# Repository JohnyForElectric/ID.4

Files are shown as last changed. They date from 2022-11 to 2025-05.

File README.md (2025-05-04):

## This repo discusses various appearance and convenience updates, tweak and retrofits for ID.4/ID.5 car family. 

_None of these are endorsed by the manufacturer, all content is provided for informational purposes only, we do not take any responsibility or liability for any damage, loss, injury or voiding warranty._

> [!TIP]
> Please, check our VW ID Talk Podcast https://www.youtube.com/@vwidtalkdotcom

Why? To make us feel better about what we drive, some of us would like to make usability changes (retrofit 360 camera system, better audio,...), improve convinience (foldable mirrors, open/closde all windows with key,...), protect the car (paint protection film, door sills,...) or change the appearance and comfort (different wheels, "black" package,...). It's up to everyone's taste. Below are some ideas...

> **Desclaimer:** All content is provided for informational purposes only. We assume no responsibility for any damage, loss, injury, or voided warranty resulting from modifications. Proceed at your own risk.

### Core principles

1.	Use high quality OEM parts, if OEM not availbale, make it look like it "belongs there"
2.	Do not touch or interfere with any high-voltage components

Below are 3 categories of changes by the level of difficulty we discuss on this page - 

| Type | Description | Simplicity | Notes |
| :--- | :--- | :--- | :---  |
| [Updates](#Updates) | OEM or vendor components manufactured for the ID. car family | L100 (Simplest) | Simple to install by following installation manaual |
| [Tweaks](#Tweaks) | Modification of existing OEM compopnents | L200-300 (Harder) | Usually no or very little "coding" or "adaptation" necessary|
| [Retrofits](#Retrofits) | Installing OEM components that were not in the vehicle for the current model year or not availbale in country of purchase | L400+ (Very hard) | Custom harness, SMD soldering and extensive "coding" / "adaptation" necessary|

### Retrofits
Retrofit is a change or addition of OEM componenets that were not available when the car was purchased. Typically, options not available in the US market or in the previous model years. 
_None of these are endorsed by the manufacturer, all content is provided for informational purposes only, we do not take any responsibility or liability for any damage, loss, injury or voiding warranty._

| Project | Description | OEM HW Feasibility | Coding Feasibility | Doable? | Works in ID.Software version and MY? | WVIDTalk Forum links |
| :--- | :--- | :--- | :---  | :--- | :--- | :---
| [Euro Style Tail Lights "ID.Light"](</Retrofits/Euro%20Style%20Tail%20Lights.md>) | Rear Euro Style top trim tail lights with animations | Feasible / Done | Feasible / Done | Yes (with workaround) | 2.1, 3.1 | [VWIDTalk Discussion](<https://www.vwidtalk.com/posts/119787/>) |
| Capacitative button replacement | Headlights, vision and multimedia capacitrative swap for Skoda Enyaq/Elroq | Feasible / Done | Feasible / Done | Electrically compatible, requires LOT of physical interfaces and cutting out parts of dash | No coding needed | [VWIDTalk Discussion](<https://www.vwidtalk.com/threads/half-way-on-capitative-buttons-replacement.18355/?post_id=316986#post-316986>) |
| 360 Area View Camera | Install 360 camera system with 4 cameras | Feasible, extra 4 cameras and 360 module required | Feasible | Yes (with caveats) | POC tested with 3.2 | [VWIDTalk Discussion](<https://www.vwidtalk.com/posts/275796/>) |
| GTX Style Diamond Pattern Accent Lights | Front bumper accent lights | Feasible | Feasible | Yes - front bumber removal required | N/A |  [VWIDTalk Discussion](<https://www.vwidtalk.com/posts/152339/>) |
| Q4 e-tron AC Control Head | A/C control panel from Q4/A3 | Possibly feasible based on the version of AC (J979) module | TBD | Tested on 2.1 - the display was ready only | TDB |  [VWIDTalk Discussion](<https://www.vwidtalk.com/posts/112946/>) |
| Ventilated front seats | Front seat ventilation | Feasible - requires 4 fans, wiring and soldering in the CECM control unit | Known, needs validation | There is a plan b (availbale conveniece CAN decoder) to avoing soldering in the CECM. Needs permananet seat cushion modification. | Validated in 3.2. |  [VWIDTalk Discussion](<https://www.vwidtalk.com/posts/292287/>) |
| Heated rear seats | Add seat heaters froi the rear seats (4 heating elements) and controller to the middle console | TBD - depands on the AC module (J979) version | Doable is supported in HW | N/A | |  [VWIDTalk Discussion](<https://www.vwidtalk.com/posts/279775/>) |
| GTI/GLI/R Steering Wheel Controls | Steering wheel buttons with "R" and "Heated Steering Wheel" buttons | Feasible | Coding & ACC Adaptation needed | N/A | N/A |  [VWIDTalk Discussion](<https://www.vwidtalk.com/posts/112011/>) |

   _OEM HW (original equipment manufacturer hardware) feasibility - determines if the original hardware (parts, control units, connectors) can be used. Coding Feasibility - determines if the existing control unit supports that project._
_None of these are endorsed by the manufacturer, all content is provided for informational purposes only, we do not take any responsibility or liability for any damage, loss, injury or voiding warranty._

### Tweaks
We define "tweak" is a change or addition where no OEM componenets exist. 

| Project | Description | Limitations
| :--- | :--- | :---
| [Driver Window Controls Haptic Feedback](</Tweaks/Driver%20Window%20Controls%20Haptic%20Feedback.md>) | Haptic feedback for the "famous" driver door window switches | All ID cars
| [Ventilated phone storage (German made cars)](</Tweaks/Ventilated%20Phone%20Storage.md>) | New fan to cool phone space and wireless charging plate | German-made ID.4 and ID.5 cars, all SW versions

### Updates
Updates use OEM or vendor components manufactured for the ID.4. 

| What | Details | More resources
| :--- | :--- | :---
| Door Sill Paint Protection Film | VW OEM Part 11A071310ZMD | https://www.amazon.de/-/en/gp/product/B08NWF3H6P 
| Frunk | Direct fit frunk insert | https://www.frunk.at/produkt/set-vw-id-4-id-5-frunk/
| Home Link Mirror | VW OEM Part 000.072.548.L | https://www.vwidtalk.com/threads/homelink-mirror.1559/
| Paint Protection Film (PPF) | Pre-cut parts from https://www.invisiblemask.com/  | https://www.vwidtalk.com/threads/3m-paint-protection-film-ppf-installed.4493/#post-69585
| Windshield protection film | https://www.stek-usa.com/windshield-film/ |  Find your local installer

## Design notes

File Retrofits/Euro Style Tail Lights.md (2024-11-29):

# Euro style taillights "ID.Light"
<div align="center">
  (Euro-styke taillights)
</div>

## Situation
There are two types of taillights available for the ID.4. The "base" style (option 8VG) and the smart "ID.Light" (option 8VP). The latter only available in Europe in higher trim vehicles. The US taillights used for model years 2021 and 2022 are simple modification of the "base" Euro. The yellow turn light LEDs in the unit are replaced for red. In addition the US spec taillight has an internal connection between the brake segment and turn segment. As such both of these segments come on during braking and when turn light is on. The coding of the CECM (J519) "Vehicle Electrical System Control Module" is adjusted accordingly in US vehicles to "Bremslicht_ist_auch_Blinklicht"=Yes (Brake light is also turn light). In addition, the taillight connector has one less pin and the wire harness one less wire. This makes it harder to retrofit yellow rear turn lights into US vehicles.

---
**NOTE**

The retrofit of EURO ID.Light into US vehicle as described below is validated as working in **ID.Software 3.1.0**.
(For ID.Software 3.1.0 the adaptation "Bremslicht_ist_auch_Blinklicht" was removed along with other six adaptations in the "Fahrlicht_Bremslicht_Standlicht_SAM" category from J519/CECM.)

**The OTA update 3.2.11** (aka VW action Code OUF7) installed correctly with this mod and no action was necessary after installation. No adaptations have changed.

---

The US model year 2023 physically removed the turn light segment from the taillight for better esthetical appearance as the brake and turn segments were separated by tail/parking segment.

The top spec "ID.Light" provides dynamic yellow turn signals and "welcome" animation via main 9 taillight segments. ID Furkan did a good video about those animations [here](https://www.youtube.com/watch?v=KCvncdPqyN0).

This article describes one of the possible approaches to retrofit the Euro-style premium taillight (ID.Light further) into US spec ID.4. While the process for retrofitting to Euro cars can be similar, the existing harness and coding will be different.

## Challenges
- The base taillights use a simple drive-by wire system for each segment, the Euro-spec ID.Light uses a LIN interface and the internal computer of the taillight drives the individual segments based on the message from LIN bus. So the lights are controlled fundamanetally differently and as such: 
  - The ID.Light has a different connector and additional signals / wires - (a) 12V connection for the internal computer and (b) a LIN bus connection to Gateway (J533)
  - The coding/adaptation of the CECM (J519) "Vehicle Electrical System Control Module" and Gateway (J533) "Data Bus on Board Diagnostic Interface" is very different. *To put the scope of adaptations in perspective - CECM has about 1,600 adaptations and Gateway around 1,000. These are way beyond the "long-coding" that is known from previous generation vehicles.*

## Approach and solutions

### Option 1: Base Euro Tail Lights for Yellow Blinker (option 8VG)
One option for yellow rear "blinker" is to replace the outer lights with base european version (left 11A 945 095 and right 11A 945 096). This option was not explored in detail, so everything further for this option is a hypothesis. (1) Additional wire(s) need to be routed to the tail light to account for a seperate brake and turn indicators, (2) adaptation of CECM (J519) needs to be adjusted. It's not known today how to change the "Bremslicht_ist_auch_Blinklicht" setting to "No", (3) the tail light connector (that is "coded" by a small notch on the side) may be different than the US "brown-coded" version. 

### Option 2: ID.Light Tail Lights for Yellow Blinker & Animations (option 8VP)
This option compared to the previuos adds the center light (11A 945 276 B). The left (11A 945 207 A) and right (11A 945 208 A) lights are available for almost same price as the base light (option 1). The amount of work seemed to be equal, so the decision was made to go with the ID.Light for this project. Also, the "coolness" of animation was unbearable not to try out. Seriously :)

Let us set the stage first. On the scale of difficulty, this project on a 3 scale Low-Medium-Hight, showed as High++. The harness is not yet commercially available (the [offer from Kufatec](https://www.kufatec.com/en/light-sight/taillights/complete-set-led-rear-lights-with-dynamic-flashing-light-for-vw-id4-e21-46455) is only for Euro vehicles and not yet tested for US vehicles), so the only option was to make it using OEM components based on the official electrical diagrams from  https://erwin.vw.com/. Another challenge is the coding/adaptation, the obvious approach was to compare US Spec vehicle coding with the coding of Pro Max ID.4 Euro . Luckily 'downtime' posted full adaptation maps on [VCDS Forum](https://forums.ross-tech.com/index.php?threads/27745/) - thank you, this helped a ton! However the inability to adapt the "Bremslicht_ist_auch_Blinklicht" setting to "No" (with VCDS or OBD11) made the entire project more complex - more in [VCDS Forum](https://forums.ross-tech.com/index.php?threads/33372/#post-281097)). We do have a workaround solution that cancels all errors on the dash and allows to "unplug" the taillights for software updates, but is not as elegant as desired... and is described below.

#### Components Needed

| What | Part Number | Notes
| :--- | :--- | :----
| 1 x Left Taillight | 11A 945 207 A | A.k.a. "MX3". Needs "blue" coded connector (the pin layout of the connector is the same, but there is a noth on a different place that prevents connecting differently "coded" connectors. The color of the connector is different to denote the different "coding".)
| 1 x Right Taillight | 11A 945 208 A | A.k.a. "MX4". _same connector as above_
| 1 x Center Light | 11A 945 276 B | A.k.a. "MX13". Comes without VW logo, needs "blue" coded connector. The connector is different than connector for MX3 and MX4.
| 2 x Blue connector for outer lights (MX3 and MX4) | 982-973-714-A | Waterproof, comes without pins and without waterproofing rings
| 2 x Blue connector for center lights (MX13) | 1K8 972 928 B | Not waterproof, the ceter light MX13 has two connectors for each side

# Harness
The harness shall deliver power (+12/14.4V), data (LIN) and for US spec vehicles additional wire for turn light. The harness starts in the internal fuse box / CECM(J519) on the driver's side and can be routed along the main harness to the back of the car, where it splits in three ways: to each side and up throught the tailgate to middle lights.
 - The two power wires go from fuse SC24 for the left and fuse SC10 for the right. The fuse slots for SC24 and SC10 are empty. Each power wire (0.5 rt/ge) wire splits at the back of the car to the tail connector T8w and T8aa (includes water insulation ring) and the lid interconnect T10e and T10f. Then continues from the lid interconnect T10h and T10i to the MX13 tail light – connectors T8s and T8aj. 
 - The LIN is routerd from Gateway/ICAS1(J533). For Pro models with "kick-to-open-tailgate" the LIN can be found at the back near park assist module (where the DCC module is on Euro cars). The LIN (0.35 vi/sw) goes to each taillight connector T8w and T8aa (w/ water insulation ring) and via the lid interconnect T10f to the MX13 T8s and T8aj. 
 - An additional wire for each side is needed on the US spec cars from J519/CECM connections - the easiest is to find the "positive connection in tail light harness" between pins 71 & 60 from the T73a connector and 8 & 27 from connector T73b (great theory, we could not easilly find the splice so we routed an extra wire). However with the "Bremslicht_ist_auch_Blinklicht"=Yes workaround we recommend to route extra wires for each side (one turn and one break signal) - so 4 in total.

## Pin to pin connections

Following table shows connections between J519/CECM and each tail-light connector. Left tail MX3 (connector T8w), center tail MX13 (connectors T8s and T8aj) and right tail MX4 (connector T8aa). 

The "Workround/US" column shows suggested connections for US vehicles in case the adaptation "Bremslicht_ist_auch_Blinklicht" *__cannot__* be changed to __no__. If "Bremslicht_ist_auch_Blinklicht"=Yes, the coding is *__expecting__* one channel to be *__coded__* as "joined turn and brake light" (last row of the table). 

---
**NOTE**

The retrofit of EURO ID.Light into US vehicle as described below is validated as working in ID.Software 3.1.0.
(For ID.Software 3.1.0 the adaptation "Bremslicht_ist_auch_Blinklicht" was removed along with other six adaptations in the "Fahrlicht_Bremslicht_Standlicht_SAM" category from J519/CECM.)

---

In addition the load management cannot be disabled by setting the "Lasttyp" to "LED_Kleinleistung_ohne_Open_Load_Diagnose" so it has to be terminated by a resistor. The resistor maximal resistance (minimal current) was determined as 400Ohms, in some situations (with low 12V battery) an error can show on the dash, so the suggested value is 300Ohms (that is approx. 50mA and 0.7W), for safety we picked 10W resistor.

For better understanding of the table, let us explain the J519/CECM light channels and essentials of coding. The J519/CECM has 29 "light channels", those can be configured and adapted with multiple different advanced functions, and the channels are numbered from 16 to 45. Those channels show in adaptation as e.g. "Leuchte 18 BLK HL A60". This means <Leuchte = Lights> <**channel #**> <**function**> <**location on the vehicle**> <**connector and pin of the J519/CECM**>. So the <**channel #**> (e.g. 18) as explained above; <**function**> (BLK=Blinker = Turn light, BR=Brems Licht = Brake Light, SL=Tail Lights, RFL=Backup light, NSL=Fog lights (not used in US spec vehicles)...); <**location on the vehicle**> (HL=Hinten Links = Rear Left, HR=Hinten Rechtes = Rear Right,...); <**connector and pin of the J519/CECM**> (A60 is connector T73**a**/pin **60**; C09 is connector T73**b**/pin **9** and B03 is connector T46**f**/pin **3**...). Ok. Seriously.

The table shows both the "logical" connections - that correspond with the adaptation channel in J519/CECM (for coding) and "physical" connection that is the actual connector and pin of the J519/CECM.

| Signal | Expected/Euro spec car: <BR> J519/CECM Logical (Physical) Connection ("Bremslicht_ist_auch_Blinklicht" = No)  | Workaround/US spec car: <BR> J519/CECM Logical (Physical) Connection ("Bremslicht_ist_auch_Blinklicht"=Yes) | Connected to...
| :--- | :--- | :----  | :----
| Turn Light | 18 BLK HL A60 (Connector T73a /60);<BR> 19 BLK HR C27 (Connector T73b /27) | 40 Zusatz hecklicht HL B03 (Connector T46f /3);<BR> 41 Zusatz hecklicht HR B20 (Connector T46f /20) | Turn Light Lamp:<BR> MX3 (Connector T8w /8);<BR> MX4 (Connector T8aa /8) 
| Brake Light | 20 BR L A71 (Connector T73a /71);<BR> 21 BR R C8 (Connector T73b /8) | 18 BLK HL A60 (Connector T73a /60);<BR> 19 BLK HR C27 (Connector T73b /27) | Brake Light Lamp:<BR>  MX3 (Connector T8w /5);<BR> MX4 (Connector T8aa /5) and<BR> MX13 (Connectors T8s /5 and T8aj /5)
| Tail/Posion Lamps | 23 SL HL C31; <BR> 24 SL HR A61 | 23 SL HL C31; <BR> 24 SL HR A61 | Not connected, only proper coding required to aviod error on the dash
| Error Cancellantion | Not necessary |  20 BR L A71 (Connector T73a /71); <BR> 21 BR R C8 (Connector T73b /8) | Coded as combined Brake and Turn Light, connected via 300 Ohm resistor to ground

## Wiring & harness photos
### Back of the vehicle
| Additional 3 wires (on top - LIN, Turn and +12V | New harness in the rear compartment | Ready to plug in
| :--- | :--- | :----
| All wires spliced with waterproofing ring | New harness, wires branch out to multiple places from here | All carefully wrapped and sealed with butyl. New blue "coded" connector that fits IQ Tail-lights  
|  |  | 

### Front of the vehicle
| Connector T73a opened and unfolded | Resistors for error cancellation | Added harness and connector
| :--- | :--- | :----
| The best way to tap into existing harness is to insert a new wire with the right pin to the connector | Secured both resistors with Arctic Silver Thermal Adhesive to stay safely in place | A brand new harness and connector to nicely accomodate all changes (optional)
|  |  | 

# Coding
[OBD11 PRO](https://obdeleven.com/en/) is a must. Higly recommend [VCDS](https://store.ross-tech.com/shop/vchv2_ent/) for exporting Ada/Adaptations maps for comparisons and coding itself... 

Below section only lists settings that are changed in the US version to accomodate the IQ Lights and to code the light channels per workaround described above. Coding will be different for Euro vehicles. For Euro vehicles we highly recommend to run an adaptation delta between your adaptations and the one that has IQ Lights from the factory. 

## Module 19 / ICAS1 / CAN Gateway

### Configure IQ Lights
  ```
- ENG253039-SFT271909-Intelligente Heckleuchte-Verbau-left tail lamp 1, installed
- ENG253039-SFT272142-Intelligente Heckleuchte-Verbau-left tail lamp 2, installed
- ENG253039-SFT272143-Intelligente Heckleuchte-Verbau-Right rear tail lamp 1, installed
- ENG253039-SFT272144-Intelligente Heckleuchte-Verbau-Right rear tail lamp 2, installed
  ```

  #### Enable light animations
  ```
- IDE12986-ENG278492-BAP configuration-Bap_fc_list_exterior_light, FF FF FF FF FF FF
- IDE12986-ENG142232-BAP configuration-HMI_exterior_light_sensitivity, 7
- IDE12986-ENG278470-BAP configuration-HMI_exterior_light_sensitivity_2, 3
  ```

  #### Enable cascading turn-lights
  ```
- IMAS12382-ENG122211-Dynamic turn signal control-Richtungs_blinken_links, active
- IMAS12382-ENG122210-Dynamic turn signal control-Richtungs_blinken_rechts, active
  ```
  
## Module 9 / J519 / CECM
  
### Light Channels

#### Brake lights
  ```
- ENG263478-ENG261250-Leuchte 18 BLK HL A60-Dimmwert ABC 18,127
- ENG263478-ENG116214-Leuchte 18 BLK HL A60-Lasttyp 18,LIN_SBBR_Versorgung_OL_Appl_55
- ENG263478-ENG116217-Leuchte 18 BLK HL A60-Lichtfunktion A 18,Brake lamp

- ENG263431-ENG259136-Leuchte 19 BLK HR C27-Dimmwert ABC 19,127
- ENG263431-ENG116233-Leuchte 19 BLK HR C27-Lasttyp 19,LIN_SBBR_Versorgung_OL_Appl_55
- ENG263431-ENG116236-Leuchte 19 BLK HR C27-Lichtfunktion A 19,Brake lamp
```
  
#### Turn-light
  ```
- ENG263436-ENG260616-Leuchte 40 Zusatz_hecklicht_HL B03-Dimming Direction DEF 40,minimze
- ENG263436-ENG260978-Leuchte 40 Zusatz_hecklicht_HL B03-Lasttyp 40,LIN_SBBR_Versorgung_OL_Appl_55
- ENG263436-ENG259008-Leuchte 40 Zusatz_hecklicht_HL B03-Lichtfunktion A 40,Blinken links aktiv
- ENG263436-ENG258714-Leuchte 40 Zusatz_hecklicht_HL B03-Lichtfunktion B 40,not active
- ENG263436-ENG258768-Leuchte 40 Zusatz_hecklicht_HL B03-Lichtfunktion D 40,Blinken links Dunkelphase
  
- ENG263464-ENG259814-Leuchte 41 Zusatz_hecklicht_HR B20-Dimming Direction DEF 41,minimze
- ENG263464-ENG261015-Leuchte 41 Zusatz_hecklicht_HR B20-Lasttyp 41,LIN_SBBR_Versorgung_OL_Appl_55
- ENG263464-ENG260996-Leuchte 41 Zusatz_hecklicht_HR B20-Lichtfunktion A 41,Blinken rechts aktiv
- ENG263464-ENG259966-Leuchte 41 Zusatz_hecklicht_HR B20-Lichtfunktion B 41,not active
- ENG263464-ENG259570-Leuchte 41 Zusatz_hecklicht_HR B20-Lichtfunktion D 41,Blinken rechts Dunkelphase 
  ```
  
#### Tail-light
  ```
- ENG263482-ENG116480-Leuchte 23 SL HL C31-Lasttyp 32,LED_Kleinleistung_ohne_Open_Load_Diagnose
- ENG263469-ENG116328-Leuchte 24 SL HR A61-Lasttyp 24,LED_Kleinleistung_ohne_Open_Load_Diagnose
```
  
#### Backup lights
  ```
- NG263493-ENG259919-Leuchte 28 RFL L C06-Dimmwert ABC 28,0
- ENG263493-ENG116406-Leuchte 28 RFL L C06-Fehlerort mittleres Byte DTC-DFCC 28,00
- ENG263493-ENG116580-Leuchte 28 RFL L C06-Lampendefektbitposition 28,00
- ENG263493-ENG116404-Leuchte 28 RFL L C06-Lasttyp 28,not_active
- ENG263493-ENG116407-Leuchte 28 RFL L C06-Lichtfunktion A 28,not active

- ENG263488-ENG116425-Leuchte 29 RFL R A72-Fehlerort mittleres Byte DTC-DFCC 29,00
- ENG263488-ENG116581-Leuchte 29 RFL R A72-Lampendefektbitposition 29,00
  ```
#### Bonus: Front lights animation (does not require IQ Tail-lights). Same as Euro coding.
  ```
- ENG253358-ENG259279-Anpassungen_Exterior_Light-Events_Szene_1,00 01 FF FF 03 04 05 FF
- ENG253358-ENG260976-Anpassungen_Exterior_Light-Events_Szene_31,14 3E 6E 3E 08 00 00 00
- ENG253358-ENG260284-Anpassungen_Exterior_Light-Events_Szene_32,00 FF FF FF FF FF FF FF
- ENG253358-ENG260168-Anpassungen_Exterior_Light-Events_Szene_4,FF FF FF FF 09 0A 0B FF
- ENG253358-ENG259646-Anpassungen_Exterior_Light-Events_Szene_5,10 11 12 FF 10 11 12 FF
- ENG253358-ENG260432-Anpassungen_Exterior_Light-Events_Szene_6,06 07 08 FF FF FF FF FF
- ENG253358-ENG258154-Anpassungen_Exterior_Light-Events_Szene_8,0C 0D 0E FF FF FF FF FF

Enables animations. Will display additional settings in Vehicle -> Exterior -> Lights menu
- ENG253358-ENG258812-Anpassungen_Exterior_Light-p_Abstand_IDG_Inszenierung,25.5 m
- ENG253358-ENG258950-Anpassungen_Exterior_Light-p_Kessy_ID,active
- ENG253358-ENG259215-Anpassungen_Exterior_Light-pa_ambExtLight_Installation,active
- ENG253358-ENG258160-Anpassungen_Exterior_Light-pa_ext_Ambiente,active

```
# Conclusion
  
And here we go. The results are amazing, the journey to get here was much harder than originally anticipated.
  
#### Videos

The brake light now spans across the side and center lights and yellow turn light is indepandent.

https://user-images.githubusercontent.com/107234448/184520870-9b423880-1967-45f5-9b03-74fa5c036585.mp4

And this is the one of two welcome animations...

https://user-images.githubusercontent.com/107234448/184521899-61f484e4-4b1e-4c20-8236-670647630f44.mp4

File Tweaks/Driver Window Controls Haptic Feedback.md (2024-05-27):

# Driver Window Controls Haptic Feedback 

<div align="center">
  (part number known as 10A 959 862 S)
</div>

## Situation
Unlinke previous VW models, there are only two driver side window switches that by default control the front driver and passenger windows. 
- To control the rear windows the REAR "soft" button (not a physical button, does not have any haptic feedback)  needs to be touched for more than 1 second, then the button lights up, and the rear windows can be controlled by the same controls that previously controlled the front windows. The button stays lit for approx. 10 seconds, then turns off, reverting the controls to the front windows. 
- If the "REAR" soft button is touched and held for 2+ seconds, it starts to blink and all four windows can be controlled at the same time :heart:. 

## Challenges
1. The REAR soft button can't be located easilly without looking. There is no "dot or mark" that can be felt with a finger to locate it more easilly
2. There is no haptic feedback in case the button is activated indicating the mode selected REAR/ALL modes
     - There is a small "chime" in the speakers once the mode is changed, but it's not too obvious and can be easily missed
     - Furthermore to activate the button with a finger, the finger must cover the button and the completely blocks the light indicator. As such it’s not possible to see the mode it entered, unless the finger is lifted and eyes taken off the road ...and more distraction from driving.

## Solution to challenge #1 - "locating the button"
...is to e.g. add two self-adhesive pads to help easily locate the touch sensitive area without looking at the location.
One of the approaches below:
<div align="center">
  Helping to locate the touch sensitive area by two self adhesive pads
</div>
This itself is a big help for me :man_dancing: :woman_dancing:

## Solution to challenge #2 - "adding haptic feedback" 

To add haptic feedback, or improve the experience even further, there are many options, couple outlined below:

Option | Details | Pros/Cons | OEM
---|---|---|---
#1 - Clone "REAR" button LED signal with a vibration motor | Once the REAR soft button lights up a vibration motor in the unit will vibrate giving a haptic confirmaton | Simple circuit, but requires tapping into the circuit board of the unit | No
#2 - Digitally process the "REAR" button LED signal and digitally manage the haptic experience | A micro-controller will receive the REAR button LED signal and control the vibration motor to create better haptic experience | As above requires tapping into the unit, has to wait approx 1 sec to "decode" the mode from the REAR button LED (blinking vs. solid on) | No
#3 - Connect to the control unit's LIN bus, process its signals and digitally control haptic experience | Use the same connector as the control unit for "snap-on" installation. The control unit has 3 wires - VCC, Gnd and LIN. The LIN bus sends the "chime" signal to the speakers, that can be used to trigger a good haptic experience | Just plug and play, but requires to decode the LIN bus, the LIN bus data may not distinguish between the REAR and ALL window modes | No
#4 - VW aka Volkswagen to come up with updated unit that would provide better experience | Go crazy VW, but please make it backwards compatible :smiley: | "Just plug and play from the OEM" | Yes

### Option #1 - Clone REAR button LED signal with a vibration motor
This was the immediate idea that felt the simplest to execute. However it requires to permanently modify the part number known as 10A 959 862 S

#### Step 1 - get the signals
Open the OEM part and get the details...

Description | Picture 
---|---
PCB Top Side - notice the touch sensitive round areas and the LEDs on the top. And window buttons areas on the lower part. Eeach window button direction has 2 stages, hence 4 pads... |  HTML image alt text Optional image title
PCB Bottom Side - notice the microcontroller in the center, LIN interface on the top middle above the 3 pin header/connector |  HTML image alt text Optional image title
PCB Top Side - detail of the REAR soft button LED |  HTML image alt text Optional image title
PCB Bottom Side - REAR soft button LED signal pads in red |  HTML image alt text Optional image title
PCB Bottom Side - REAR soft button LED signal pads with soldered wires (yellow positive signal) |  Optional image title
PCB Bottom Side - REAR soft button LED signal pads with soldered wires (yellow positive signal for LED, green negative signal for LED, black ground, red VCC) |  Optional image title

#### Step 2 - design the circuit
A quick design with Opto-coupler to physically separate the input (yellow and green wires) and the 12V/14.4V power line (red and black wire) to protect the components and the LIN bus. The signal enters the opto-coupler ("solid state relay") [LCA110]([url](https://www.digikey.com/en/products/detail/ixys-integrated-circuits-division/LCA110/203107)) via resistor R1 (100 Ohms). The two MOSFETs (I know I know the schematics does not show MOSFET, but a regular BJT transistor) on the output turn on the vibration motor. The resistor R2 limits the total current and it's size depends on the type of vibration motor. D1 and D2 1N4148 protect the components (D1 negative spikes from entering into the circuit, D2 from induction spikes when the motor turns off). Not on the picture - added C1 (0.1 uF) to the power rail.

<div align="center">
  (part number known as 10A 959 862 S)
</div>

#### Step 3 - test the circuit
Time to test if it works. This design used a cheap vibration motor, R2 was 330 Ohms.
<div align="center">
  (part number known as 10A 959 862 S)
</div>

#### Step 4 - design and test
Time for more rugged design, used the same vibration motor that VW uses in the steering wheel touch buttons and added variable resistors to precisely adjust the haptic experience. Both resistors ended up around 100 Ohms (the static + variable).

<div align="center">
  (part number known as 10A 959 862 S)
</div>
<p>
...then 3D printed a "vibration motor holder" from flexible filament (the red brick on the bottom). So, it is easier to attach and to provide cushioning around the vibration motor. Protected all with beloved Tesa tape for a "professional" look :wink:

<div align="center">
  (part number known as 10A 959 862 S)
</div>

With ID software version 3.1 the 12V rail is more stable, so an intended Zener diode is not necessary. Was hoping that the id.7 / 20214 ID.4/5 will introduce a 4 switch version and I'd just swap this VW experiment for a real thing. Since that did not happen, I did wrap the handle in VVIVID XPO Black Leather Suede for luxury look. And it really looks great... 

Ok so I feel this is the end of this mod... :) Off to the next one...

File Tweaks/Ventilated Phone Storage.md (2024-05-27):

# Center Console Ventilation for your phone (German made cars)
<div align="center">
  (Center console)
</div>

## Situation
Over the years we got multiple warnings on our phones about paused charging due to its high temperature. This is a feature of the phone to prevent battery demage and we believe it occured on both wireless and cable charging. We also believe that the rootcause was a bug in certain versions of iOS. These bugs were resolved in one version but appreaded again on another, so we set of on a quest to solve this once for all - by introducing airflow to cool the space. How? By adding a small fan into the center console to provide active cooling to both the phone and the OEM wireless charging plate (R126). 

3 outcomes that drove this design:
1) Cool the phone and the charging plate (R126)
2) No parts visible from the inside of the vehicle (including wiring)
3) Fan must be silent

### Quick summary
We have not explored center console ventilation in US made cars as those have a different center console. This tweak is specifically for German-made 2021 and 2022 cars (cars with two separate arm rests for the driver and passenger). We have made multiple updates to the center console (1) introduced openings to allow air flow, (2) added 120mm computer fan with controller, (3) added additional heat sink to the built-in phone wireless charging plate (R126). The fan is directing airflow to the phone itself, but also to the charger baseplate (R126) as apparent from the diagram below.

Overall Airflow | Phone Airflow 
---|---
(Center console) | (Center console)

## How we did it
Since this is not an OEM mod, there is no coding necessary. Unlike other mods in this repo, this one makes permanent modifications to the center console to allow airflow. These modifications are not visible from the outsode.

### Parts for retrofit
There are 2 key parts for this retrofit - the fan with fan controller and additional heatsink for the OEM wireless phone charging plate (R126). The additional heatsink is optional, but we expect it to improve temperature comfort of the components inside the OEM wireless phone charging plate (R126) that sits below the phone and thus should help to reduce the phone heating problem. 

This design uses fixed RPMs for the fan (not temperature depandant), the task of the fan controller is to manually fine-tune the right airflow and minimize any noise. We believe that any mod must be at least OEM quality, as such we've selected high quality Noctua computer fan and a Noctua fan controller (that allows us to set the desired aiflow that cools, but can't be heard). 

What | Part Number | URL | Notes
---|---|---|---
1 x Noctua 120mm slim PWM fan | NF-A12x15 | https://noctua.at/en/nf-a12x15-pwm | Main component
1 x Noctua fan grill | NA-FG1-121 Sx2 | https://noctua.at/en/na-fg1-12 | Grill to protect the fan blades from intake side
1 x Noctua PWM fan controller | NA-FC1 | https://noctua.at/en/na-fc1 | Module for setting constant fan speed
1 x (Optional) Heatsink | Aluminium heatsink | https://www.amazon.com/gp/product/B07D9ZTTN2/ | Additional cooling for the OEM wireless charge plate. Only one is nedded. 
1 x (Optional) Thermally conductive adhesive | 8329TFF | https://www.amazon.com/gp/product/B07D18R5Z5/ | Adhesive to attach the additional heat sink (screws or rivets can use used instead of the adhesive).

### Connections
The system uses Noctua fan controller to drive and adjust the speed of the fan and a primite power supply. The power supply has automotive 2A fuse, uses 4 rectifiers for isolation and to drop the voltage by ~2.8V, so the opertating voltage of the controller and fan is not exceeded. Two capacitors buffer and filter the power line. The fan controller is set to low speed and the total power consumption for our fan speed setting is 30mA (less than 0.4W).
The ground (GND) is connected to the Phone Charging Plate harness (R126) (brown wire) and +12V power to the KL15 (providing +12V ONLY if the ignition is ON). KL15 is available at the back of the center console, the power for the rear USB charging module (U37) is KL15 (red/blue wire). PLEASE NOTE the power to the phone charging pad (R126) and the front USB sockets is KL30, which means it's directly connected to the 12V battery (via fuses of course) without any interruption. So if the fan would be directly connected to that rail, it would not stop.

Simplified electrical diagram 

(Wiring diagram)

### Placement of parts
The 120mm slim fan is perfectly fitting between metal clips of the front cover and the clips of the interior light for the center console. The downside of the 120mm fan is that the interior light uses a light pipe that needs to be re-designed. The replacement can be easilly 3D printed from transparent filament (attached STL file for details). Optionally, a smaller 92mm fan can be used to keep the light pipe as is.

Step | Photo | Notes 
---|---|---
1 - Removed the cupholder | (Cupholder removal) | The bigger the pry tool the better, taped the surface to protect form sctraches.
2 - Drilled holes |  (Cupholder removal) | Drilled sixteen 10mm holes around the light pipe assembly on top and 5 in the front (see next photo). The number and location depands on the fan selection.
3 - Trimed the storage compartment mat |  (Trim storage compartment mat) | Trimmed the top mat by 18mm to allow more airflow. Once the cupholder on the top is installed the only light is the ambient light.
4 - Made and tested power supply |  (Cupholder removal) | Made the power supply and integrated the fan controller and fuse into small plastic box. Added a connector for easy future upgrades.
5 - Prepared the fan and tested setup |  (Cupholder removal) | Attached the fan grill on the intake side (bottom on the picture) with the long anti-vibration mounts included with the fan. Those are AWESOME! 
6 - Installed fan |  (Fan) | The 120mm slim fan is perfectly fitting between the metal clips of the front cover and the clips of the ambient light for the center console. Drilled additional 4mm holes to pull the fan mounts through to make sure the fan is even more secure. Moved the Ambient Light LED Module (L193) to the top and made new light diffusor. 
7 - (Optional) Additional heatsink for charging plate (R126) |(J126 additional heatsink)| Made sure no sharp edges exist on the new heatsink...

Done!

## Conclusion
Interesting project - a good deep dive into few ventilation areas. Hopefully a good primer to go into ventilated seats.

## To geek around a bit more - if you are interested...
The fan controller is using PIC microcontroller https://www.microchip.com/en-us/product/PIC12F1571. Interesting automotive components https://www.microchip.com/en-us/solutions/automotive-and-transportation/body-electronics/heated-cooled-seats. Lot of cool stuff :) Another interesting descovery is this LIN controller https://www.melexis.com/en/product/MLX81108/Single-Channel-LIN-RGB-Slave-Ambient-Light-Controller that is used in ID.4's ambient lights :)

In case you are wondering how the OEM VW charging pad R126 looks inside - here is a sneak peak
1) Heatsink on the bottom removed
(J126 additional heatsink)

2) Charging coils in detail
(J126 additional heatsink)

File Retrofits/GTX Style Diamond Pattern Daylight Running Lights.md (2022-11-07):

# GTX Style Diamond Pattern Accent Lights 

<div align="center">
  (GTX Diamond-style accent light)
</div>

## Situation
The GTX version of ID.4 and ID.5 has two diamond-style accent lights in the front bumper. Let's get two misconceptions out of the way - (a) the accent lights are not configured from the factory as a Day Time running light /DLR/ (even despite it's called DLR in the official wiring diagram) and (2) it's not a front fog light. It's an accent light that turns on with the front headlights.

### More details
The non-GTX versions have the same shape of opening in the front bumber that is used to (1) intake air for optimizing aerodynamics, (2) houses one of the front parking sensors. The GTX version adds a third function - a cool diamond-style accent lights. So for GTX this part of the bumper has 3 functions: (1) air intake, (2) place for parking sensor and (3) accent light.

## Retrofits and mods
There are two usual steps to retrofits and mods (1) physical parts and (2) coding. Let's get to each one-by-one.

### Parts for retrofit

There are 3 key parts for each side - light module, bumper trim and internal bumper reinformecemt. Installation requires to remove the front bumper.

What | Part Number | Notes
---|---|---
1 x Left Light Module | 11A 941 055 A |  One light module for all 3 lenses, known as L377
1 x Right Light Module | 11A 941 056 A | One light module for all 3 lenses, known as L378
1 x Left Bumper Trim | 11A 807 763 A | "Glossy" cover for light module
1 x Right Bumper Trim | 11A 807 764 A | "Glossy" cover for light module
1 x Left Bumper Reinforcement | 11A 807 884 B | Specific to slot the lighht module
1 x Right Bumper Reinforcement | 11A 807 883 B | Specific to slot the lighht module
2 x Connector | 4F0 973 702 F | "Wet" connection to bumper harness

### Harness and pin to pin connections
Despite of all expectations, both light modules are connected to the front headlights MX1 (connector T14k /8) and MX2 (connector T14l /8) and not the CECM/J519. It's a simple two wire connection, one wire runs to each headlight and the other one is connected to the ground. The harness is routed via the bumper connector interconnect (TSFVL).

### Coding
To adapt these light modules, the head lights D6:Light Control Left (A31) and D7:Light Control right (A27) adaptations/coding need to be adjusted. The "coding/adaptation" via VCDS and OBD11, is not yet known. The only "hint" in the adaptation channel "NG178996-VehicleEquipmentCode And ProductionNumberCombination", but it has all zeroes across 12 x 8 bit numbers so the "current" state can't be determined.

The only clue we were able to find is the list of LED channels, their functions and dimming levels based on the funtion:

Channel 1-12 (rows) <BR> Mode/function (columns) <BR> PWM value (%) | Assumend Function | Brigtness Class | Hi-Beam | Parking | Low-Beam | Poor Wether + Low-Beam | Trun Light | Turn + Parking | DLR
---|---|---|---|---|---|---|---|---|---
1 | Poor Weather / Corner Light |	LK1 ||||75.6
2 | Hi-Beam	| LK2 |72.5
3 | DLR & Position | LK2 ||100|5.6|5.6|||100
4 | Low-Beam | LK2	|||100|100
5 | Hi-Beam |	LK2 |100
6 | DLR & Position | LK2||62.8|62.8|62.8|||62.8
7 | Light bar (side marker) | K1||100|100|100||100
8 | Turn light | LK1 |||||100|100
9
10
11
12

## Conclusion
  
The actual retrofit requires many OEM parts and removing the front bumper. There could be simpler options for adding non-OEM style LED DLR mini lights to each side to mimic the 3 diamond lights. We did not embark on this route as the longevity of non-OEM components is not superb (even for high-quality aftermarket brands, such as [VLEDs]([url](https://www.vleds.com/)) or [Morimoto]([url](https://www.morimotohid.com/))). 
  
Due to complexity of this retrofit (front bumper removal) - one consideration is to make additional retrofits at the same time in the front bumper (e.g. Front Camera, additional Park Pilot sensors, etc.) and connect the GTX-style accent lights to either an existing accent light or to a light channel on CECM/J519 for ultimate customizability.

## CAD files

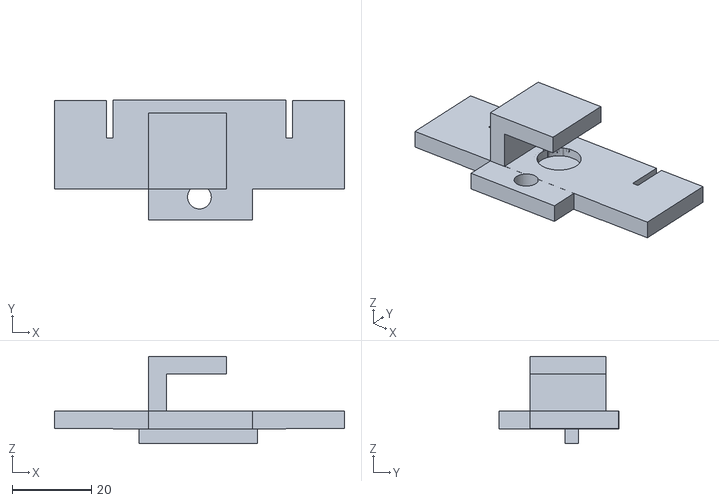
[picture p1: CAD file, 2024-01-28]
Retrofits/STL/Ambient Light Diffusor_FINAL.stl
73.4 x 30.3 x 22.1

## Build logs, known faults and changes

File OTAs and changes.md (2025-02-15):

## This page goes deeper into changes made by OTA (over-the-air) and workshop (ODIS) updates

A reference page for observed module changes for 2021 ID.4 AWD US specification after OTA (Over-the-air) and worshop (ODIS) updates.

## FUTURE Confirmed & upcoming

## PAST

### ID.software version 3.5.11 (OTA & workshop ODIS) - also known as 919A or "Black screen"

| Address | Module | Sofware version before | Sofware version after
| :--- | :--- | :--- | :---
| 01 | Engine (J623-EBRA) | 2222	| 2603
| 03 | ABS Brakes (J104) | 0524 | 0526
| 09 | Cent. Elect. (J519) | 0307 | 0311
| 19 | CAN Gateway (J533) | 0299 | 0329 
| 5F | Information Electr. (J794) | 0561 | 1751
| 6C | Back-up Cam. (J772) | 0394 | 0397
| 75 | Telematics (J949) | 0664 | 0686
| C6 | Batt. Chrg. (J1050) | 1019 | 2022
| 8123 | App server 1 system 1 adaptive (SWC4) | 0299 | 0329
| 8124 | App server 1 system 2 Java (SWC5) | 0299 | 0329
| 8125 | App server 3 system 1 infotaint. (SWC6) | 0561 | 1751
| C002 | SW Cluster Embedded (SWC2) | 0299 | 0329
| C003 | SW Cluster Housekeeping (SWC3) | 0299 | 0329 

### ID.software version 3.2.13 (OTA October 2024) - also known as OUJ9

Our take - progress and actual update process not great (more on [VWIDTalk](https://www.vwidtalk.com/posts/296230/)), changes in the actual payload likely aligned with the official "OTA improvements" messaging as all ICAS systems were updated. No changes to custom adaptations in 19 CAN Gateway (J533) surprisingly. The hypothesis is that there were no code changes for the actual Gateway section of the module. 

Other observations - (1) update process very clunky and (2) massive amount of "communication" errors floded all modules after update. This likely happened during update and the update did not perform clean-up.

##### Software versions

| Address | Module | Sofware version before | Sofware version after
| :--- | :--- | :--- | :---
| 19 | CAN Gateway (J533) | 0292	| 0299
| 8123 | App server 1 system 1 adaptive (SWC4) | 0290 | 0299
| 8124 | App server 1 system 2 Java (SWC5) | 0290 | 0299
| C002 | SW Cluster Embedded (SWC2) | 0290 | 0299 
| C003 | SW Cluster Housekeeping (SWC3) | 0290 | 0299 

### ID.software version 3.2.12 (OTA July 2024) - also known as OUH1
Official VW [link](https://www.vw.com/en/owners-and-services/connectivity-and-apps/vehicle-software-updates/electric-vehicle-software-updates/electric-vehicle-software-update-3-2.html/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)

Official version info "This software update provides minor bug fixes and enhances multiple systems. Enhancements include increased accuracy in the Travel Assist function, optimizations to the over-the-air software installation process, improvements to climate control and enhancements to the defogging function. This update is a prerequisite for future features.”

Our take - based on the modules updated - enhancements in travel assist and climate plausible, but no changes observed while driving. OTA software update process enhancements - unlikely due to no changes in modules such as Telematics, or any ICAS modules. The module that failed the update and bricked our car was 3C and/or A5. More [here](https://www.vwidtalk.com/posts/286642/). There also were additional changes to all door modules, likely related to door handle recall that was not advertised in the official description.

##### Software versions

| Address | Module | Sofware version before | Sofware version after
| :--- | :--- | :--- | :---
| 03 | Brakes (J104) | 0518	| 0524
| 08 | HVAC (J979) | 0425	| 0460
| 16 | Steering Wheel (J527) | 0071	| 0072
| 23 | Brake Booster (J539)	| 0625 | 0626
| 3C | Lane Change (J1086) | 0287	| 0289
| 42 | Driver Door (J386)	| 0550 | 0551
| 52 | Passenger Door (J387) | 0550 | 0551
| A5 | Frt Sens. Driv. Assist (R242) | 5321 | 5322
| BB | Door Rear Driver (J388) | 0550	| 0551
| BC | Door Reas Pass (J389) | 0550 | 0551

#### Adaptations changes
Please note - any "custom/after market coding" is reset to original values

| Address | Module | Adaptation name | Value before | Value after
| :--- | :--- | :--- | :--- | :---
| 03 | Brakes (J104) | No changes |||
| 08 | HVAC (J979) | No changes |||
| 16 | Steering Wheel (J527) | IDE07159-ENG273891-Control module switch-off: counter-Bus KnockOut_Ctr | 05 | 07
| 23 | Brake Booster (J539)	| No changes |||
| 3C | Lane Change (J1086) | IDE07159-MAS05583-Control module switch-off: counter-Data bus | 3 | 1
| 42 | Driver Door (J386)	| IDE07159-MAS05583-Control module switch-off: counter-Data bus | 3 | 0
| 52 | Passenger Door (J387) | IDE07159-MAS05583-Control module switch-off: counter-Data bus | 3 | 0
| A5 | Frt Sens. Driv. Assist (R242) | No changes  | |
| BB | Door Rear Driver (J388) | IDE07159-MAS05583-Control module switch-off: counter-Data bus	| 3 | 0
| BC | Door Reas Pass (J389) | IDE07159-MAS05583-Control module switch-off: counter-Data bus | 3 | 0

## Interesting links
https://www.meinid.com/wiki/entry/6-software-versionsst%C3%A4nde-%C3%BCbersicht-3-x/

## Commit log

2022-07-10 Create Driver Window Controls Haptic Feedback
2022-07-10 Update Driver Window Controls Haptic Feedback
2022-07-10 Create Driver Window Controls Haptic Feedback.md
2022-07-10 Update Driver Window Controls Haptic Feedback.md
2024-03-24 Create 360 Area View Camera
2024-03-24 Rename Ambient Light Diffusor_FINAL.stl to Retrofits/STL/Ambient Light Diffusor_FINAL.stl
    [Ambient Light Diffusor_FINAL.stl]
2024-03-24 Rename Driver Window Controls Haptic Feedback.md to Tweaks/Driver Window Controls Haptic Feedback.md
2024-03-25 Current list of tweaks and retrofits
2024-05-27 Update Driver Window Controls Haptic Feedback.md
    Fixed typos...
